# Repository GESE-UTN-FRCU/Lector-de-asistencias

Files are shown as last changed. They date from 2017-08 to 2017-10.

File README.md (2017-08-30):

# Proyecto lector de asistencias

Este proyecto es un lector de tarjetas RFID que envia el codigo leido junto a una fecha y hora y la IP del dispositivo. Este sistema fue diseñado para implementarse en la UTN-FRCU.

## Componentes utilizados:
+Arduino nano
+DS3231
+ENC28J60
+RC522
+LCD 16x2

## Integrantes:

+Alfaro Diego

+Chichi Manuel

+Garcia Alejo

+Venditti Juan Pablo

## Profesor:

+Hoet Leonardo

### TO DO (segun importancia)

+Cambiar headers a librerias bien planteadas.

+Chequear overflow del millis o hacer un reset por mes.

+Agregar seguridad a el dispositivo.

+

### Secciones:

+LectorUTN      - Contiene el codigo arduino en C del lector (este se sube en .

+Diagramas PCB  - Contiene los diagramas de las conexiones fisicas del lector.

+Pagina web     - Contiene la pagina web a la que enviara datos el lector.

# MANUAL DE USUARIO

## Configuración del dispositivo

Para el funcionamiento del sistema, primero es necesario establecer su configuración inicial. En esta, se tendrá que asignar al dispositivo un gateway (dirección IP del modem), una dirección ip del dispositivo, una dirección ip del servidor, una máscara de subred y un puerto (80 por defecto). 
Para realizar esta configuración se debe ingresar al modo de configuración del dispositivo. Para entrar al modo de configuración el usuario tiene que presionar el botón correspondiente al iniciar el sistema, cuando la pantalla está vacía.
Una vez que el dispositivo se encuentra en modo de configuración, es necesario acceder a través de un navegador web a la ip por defecto del modo de configuración “192.168.8.152”, y asi podrá acceder a la siguiente página web.

Una vez dentro de la página web, se deberá completar los campos correspondientes y oprimir el botón “Guardar”. Posteriormente, el sistema se reiniciará y los valores ingresados a través de la página de configuración quedarán asignados.
ADVERTENCIA: Una vez pasado el dispositivo a modo configuración, todas las lecturas guardadas en memoria serán eliminadas.

## Modo lector de tarjetas

Para llevar a cabo el proceso de lectura de tarjetas, solo es necesario pasar la tarjeta a corta distancia por delante del dispositivo.

Es necesario tener en cuenta ciertos criterios para que el dispositivo se encuentre disponible para la lectura de tarjetas:
El dispositivo tiene que haber sido previamente configurado (Ver sección “Configuración del dispositivo” para más información).
El dispositivo se debe encontrar disponible para leer tarjetas, mostrando en su pantalla el mensaje “Pasar tarjeta”.
El dispositivo debe estar fuera de horario de envío de datos, en este caso se mostrará en su pantalla el mensaje “No disponible”.
El dispositivo no se debe encontrar en modo configuración, mostrando en pantalla “Modo config.”
El dispositivo actualizará su fecha y hora realizando una petición al servidor cada dos horas. Cuando esto sucede, se mostrará un mensaje “Actualizando...” en la pantalla.

## Modo envío de datos

Este modo consiste en el envío al servidor de los datos recolectados en las últimas lecturas y que no hayan sido enviados y confirmados por el servidor previamente.
Este modo se encuentra disponible en el horario entre las 2 a.m. y las 4 a.m. a lo largo de todos los días del año.

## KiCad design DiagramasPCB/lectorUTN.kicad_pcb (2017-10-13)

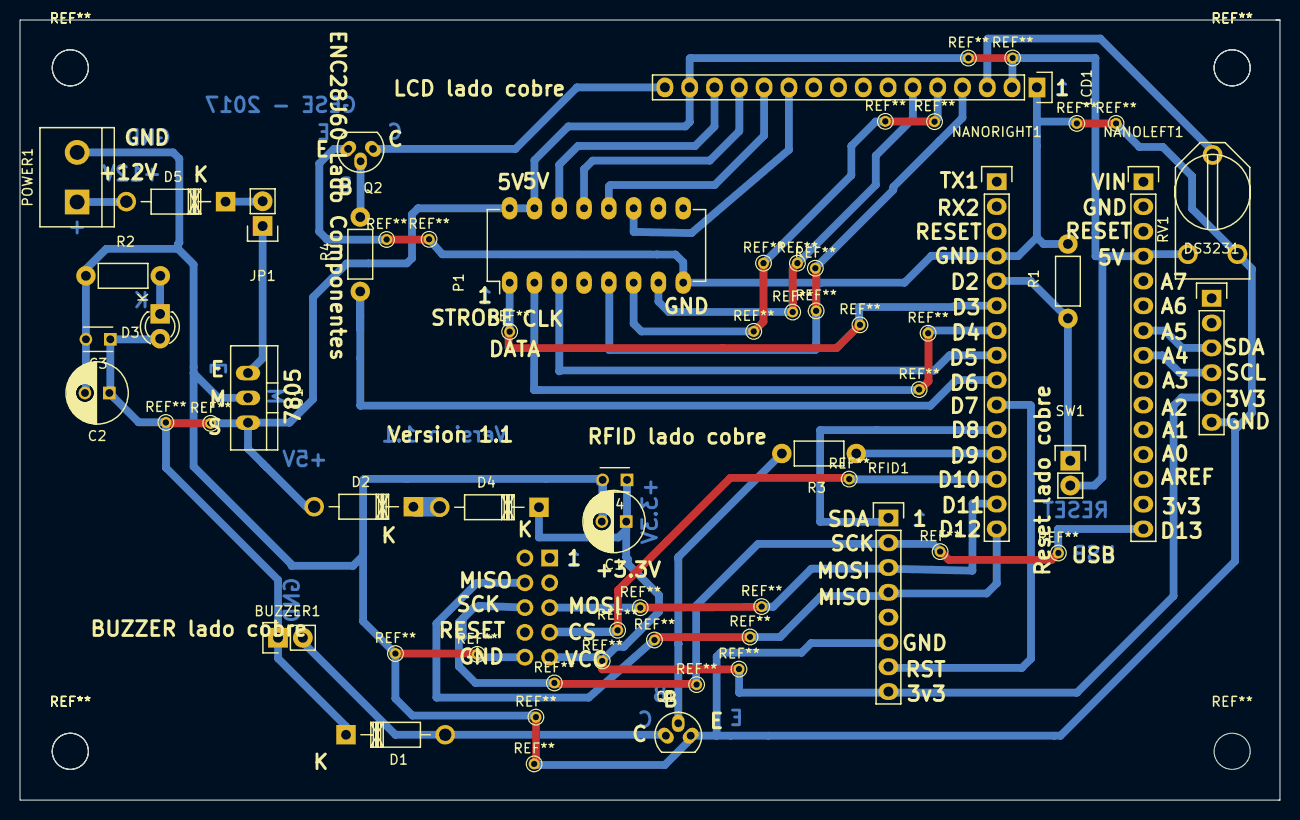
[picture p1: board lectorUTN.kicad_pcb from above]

Board: 2 copper layers, 129.0 x 79.9 mm, 28 parts (1 on the bottom side), 34 nets.

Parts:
BUZZER1: CONNECTOR_BUZZER; Pin_Header_Straight_1x02
C1, C2: 10x16; C_Radial_D6.3_L11.2_P2.5
C3, C4: 0.1; C_Disc_D3_P2.5
D1, D2, D4, D5: 1N4007; Diode_DO-41_SOD81_Horizontal_RM10
D3: LED_3mm; LED-3MM
DS3231: CLOCK; Pin_Header_Straight_1x06
ENC28J60: ETHERNET; Pin_Header_Straight_2x05
JP1: JUMPER; Pin_Header_Straight_1x02
LCD1: DISPLAY_LCD; Pin_Header_Straight_1x16
NANOLEFT1: NANO_LEFT_CONN; Pin_Header_Straight_1x15
NANORIGHT1: NANO_RIGHT_CONN; Pin_Header_Straight_1x15
P1: CD4094; DIP-16_W7.62mm_LongPads
POWER1: +12; bornier2
Q1, Q2: BC337; TO-92_Molded_Narrow_Oval
R1, R3: 1k; Resistor_Horizontal_RM7mm
R2: 220; Resistor_Horizontal_RM7mm
R4: 1K; Resistor_Horizontal_RM7mm
RFID1: RFID; Pin_Header_Straight_1x08
RV1: 1K; RV2X4
SW1: RESET; Pin_Header_Straight_1x02
U1: 7805; TO-220_Neutral123_Vertical

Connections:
unnamed: BUZZER1.1, C2.1, C3.1, D1.1, D2.2, D3.2, LCD1.2, LCD1.15, NANOLEFT1.4, P1.15, P1.16, RV1.1, SW1.2, U1.3
unnamed: BUZZER1.2, D1.2, Q1.1
unnamed: C1.1, C4.1, D4.1, DS3231.5, ENC28J60.9, RFID1.8
unnamed: C1.2, C2.2, C3.2, C4.2, DS3231.6, ENC28J60.10, LCD1.1, NANORIGHT1.4, P1.8, POWER1.2, Q1.3, R1.2, R2.1, RFID1.6, RV1.3, U1.2
unnamed: D2.1, D4.2
unnamed: D3.1, R2.2
unnamed: D5.1, JP1.2
unnamed: D5.2, POWER1.1
unnamed: DS3231.3, NANOLEFT1.7
unnamed: DS3231.4, NANOLEFT1.8
unnamed: ENC28J60.4, NANORIGHT1.15, RFID1.4
unnamed: ENC28J60.5, NANORIGHT1.14, RFID1.3
unnamed: ENC28J60.6, NANOLEFT1.15, RFID1.2
unnamed: ENC28J60.7, NANORIGHT1.13
unnamed: JP1.1, U1.1
unnamed: LCD1.3, RV1.2
unnamed: LCD1.4, P1.5
unnamed: LCD1.5, P1.6
unnamed: LCD1.6, P1.7, Q2.3
unnamed: LCD1.11, P1.11
unnamed: LCD1.12, P1.12
unnamed: LCD1.13, P1.13
unnamed: LCD1.14, P1.14
unnamed: LCD1.16, Q2.1
unnamed: NANORIGHT1.5, R1.1, SW1.1
unnamed: NANORIGHT1.6, P1.1
unnamed: NANORIGHT1.7, P1.2
unnamed: NANORIGHT1.8, P1.3
unnamed: NANORIGHT1.9, R4.1
unnamed: NANORIGHT1.10, RFID1.7
unnamed: NANORIGHT1.11, RFID1.1
unnamed: NANORIGHT1.12, R3.1
unnamed: Q1.2, R3.2
unnamed: Q2.2, R4.2

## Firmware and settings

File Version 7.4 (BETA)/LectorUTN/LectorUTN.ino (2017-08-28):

/*
 * Lector - UTN 
 * 
 * Grupo de investigacion
 * 
 * Version 7.4 - 28/08 - 
 * 
 * Alfaro Diego
 * Chichi Manuel
 * Garcia Alejo
 * Venditti Juan Pablo
 * 
 */

#include "main.h"

void setup () {
  // Iniciar todos los componentes
  // fisicos del sistema.
  iniciarSistema();
}

void loop () {
  // Si se recibe un paquete y el sistema esta en modo configuracion se envia la
  // pagina de configuracion al cliente. De lo contrario, accede al modo normal.
  routerModo(paqueteEthernet());
}

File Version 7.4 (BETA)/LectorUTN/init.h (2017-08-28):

static void activarModoConfig () {
  EEPROM.write(ADDR_MODO_CONFIG,true);
  Serial.print("ModoConfig");
  delay(2000);
  reiniciarSistema();
}

static void desactivarModoConfig () {
  EEPROM.write(ADDR_MODO_CONFIG,false);
  Serial.print("ModoNoConfig");
  delay(2000);
  reiniciarSistema();
}

static void iniciarComponentes(){
  Wire.begin();
  Serial.begin(57600);
  SPI.begin();
  rfid.PCD_Init();  
  lcd.begin(16,2);
  
  pinMode(PIN_ETH_SDA, OUTPUT);
  digitalWrite(PIN_ETH_SDA,HIGH);
  
  pinMode(PIN_MFRC522_SDA, OUTPUT);
  digitalWrite(PIN_MFRC522_SDA,HIGH);

  pinMode(PIN_MODO_CONFIG, INPUT);

  // Obtiene de memoria EEPROM el ultimo numero de la ip.
  byte ultimoValorIp = EEPROM.read(ADDR_MYIP+3);
  // Asignar a "minutos calculados" un numero aleatorio
  // en base al ultimo numero de la ip.
  minutosCalculados=ultimoValorIp/5;

  //Lee el indice guardado en memoria y lo guarda en la varible indice
  leerIndice();
  
  #if SERIAL_DEBUG
    Serial.print(F("Config: "));
    Serial.println(EEPROM.read(ADDR_MODO_CONFIG));
    Serial.print(F("Ind: "));
    Serial.println(indice);
    Serial.print(F("MinCalc: "));
    Serial.println(minutosCalculados);
  #endif


  // Iniciar la pantalla LCD.
  iniciarLCD();
  iniciarLogoLCD();

  // La mac del dispositivo tiene asignado en el ultimo valor
  // el numero del ultimo valor de la direccion ip.
  mymac[5]=ultimoValorIp;

  // Chequear estado del pulsador.
  // Si esta apretado activar MODO_CONFIG.
  byte pulsador;
  delay(2000);
  pulsador=digitalRead(PIN_MODO_CONFIG);
  if (pulsador==HIGH) activarModoConfig();
  
  // Verificar que funcione correctamente la placa Ethernet.
  if (ether.begin(sizeof Ethernet::buffer, mymac, PIN_ETH_SDA) == 0){
    #if SERIAL_DEBUG
      Serial.println(F("FailedEthernetController"));
    #endif
    cambiarLineaLCD("Error de HW");
    while(1);
  }
}

static void iniciarSistema(){
  // Iniciar todos los componentes físicos del sistema.
  iniciarComponentes();
  
  if(chequearModoConfig()){
    #if SERIAL_DEBUG
      Serial.println(F("Modo config activado"));
    #endif
    cambiarLineaLCD("Modo config.");
  }else{
    #if SERIAL_DEBUG
      Serial.println(F("Modo config desactivado"));
    #endif
    cambiarLineaLCD("Iniciando...");
    // Iniciar en 0 los valores de los codigos de las tarjetas.
    for(byte i=0;i<sizeof(codigo_actual);i++){
      codigo_actual[i]=0;
      ultimo_codigo[i]=0;
    }
    // Cargar la configuracion desde la EEPROM.
    cargarDesdeEEPROM();
  }
  
  // Asignar la configuracion de la placa Ethernet usando
  // los valores estaticos extraidos de la EEPROM.
  ether.staticSetup(myip, gwip, dnsip, netmask);
  
  delay(1000);

  // Asignar la ip del servidor a la placa Ethernet.
  ether.copyIp(ether.hisip, hisip);

  #if SERIAL_DEBUG
    mostrarConfiguracionEthernet(true);
    mostrarConfiguracionHora();
  #endif

  if(!chequearModoConfig()){
    // Si el sistema esta en MODO_CONFIG se chequea la conexion
    // haciendo ping al servidor.
    if(chequearConexion(ether.hisip,imprimirIntento)){
      // Si se verifica la conexion al servidor se muestra que el sistema
      // esta conectado y sigue funcionando correctamente.
      while(ether.clientWaitingGw())ether.packetLoop(ether.packetReceive());
      cambiarLineaLCD("Conectado");
    }else{
      // Si el sistema no puede verificar la buena 
      cambiarLineaLCD("Verificar conex.");
      #if SERIAL_DEBUG
        Serial.print(F("NoConex"));
      #endif
      delay(2000);
      reiniciarSistema();
    }
  }else{
    cambiarModo(MODO_CONFIG);
  }
}

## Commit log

2017-08-29 Diagramas PCB
    [lectorUTN.dsn, lectorUTN.kicad_pcb, lectorUTN.sch]
2017-10-13 DiagramasPCB actualizados
    [lectorUTN.dsn, lectorUTN.kicad_pcb, lectorUTN.sch]
